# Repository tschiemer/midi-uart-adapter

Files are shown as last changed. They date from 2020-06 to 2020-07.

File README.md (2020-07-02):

# midi-uart-adapter

PCB layout for a simple MIDI (In-Through-Out) / UART - Adapter according to MIDI 1.0 Specification

Does not directly include footprints for MIDI or TRS plugs but rather provides headers such as to more easily allow customization.

Also allows to use different voltage levels for RX, TX respectively (please use different resistors according to recommendations).

https://github.com/tschiemer/midi-uart-adapter

According to simple table-top tests using a Behringer BCF2000 all three connections (in, through, out) work as expected.

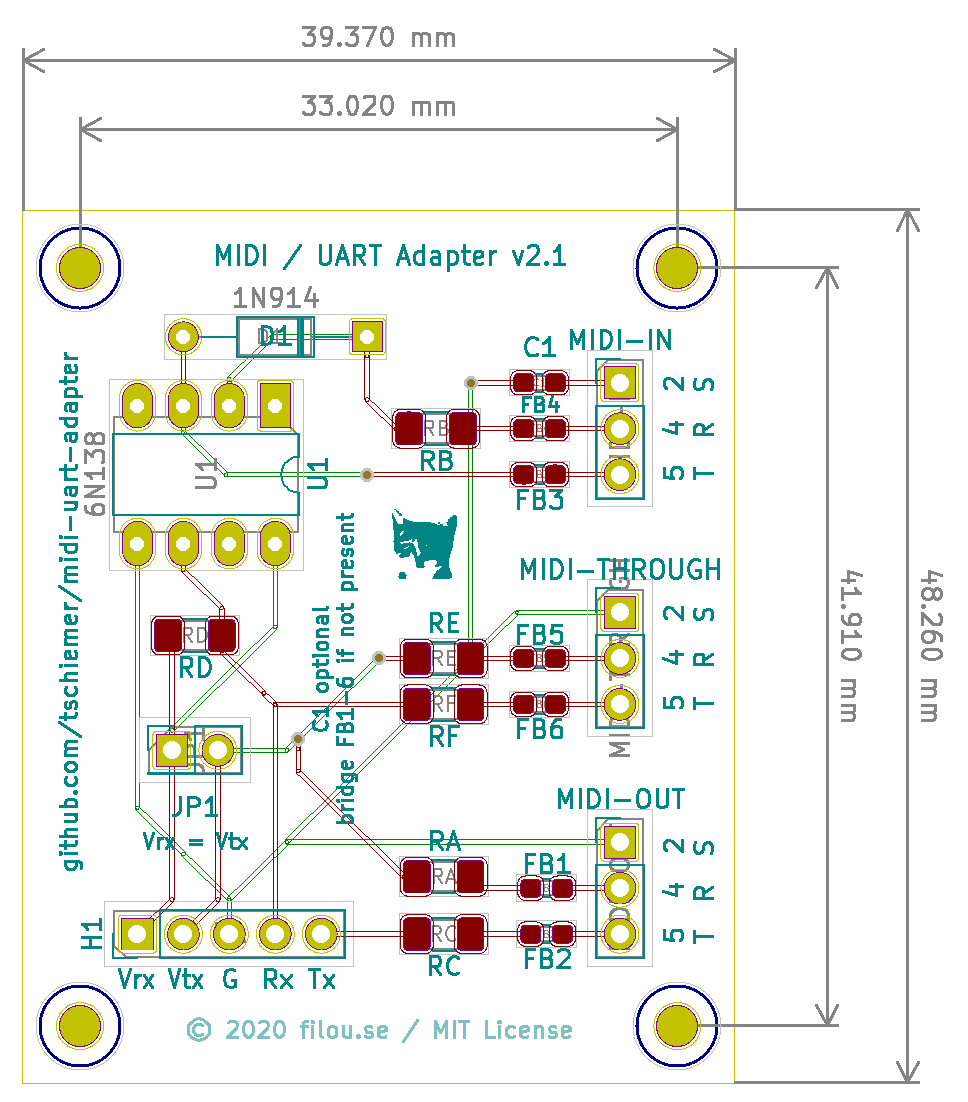
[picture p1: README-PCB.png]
PCB


## Parts

- [LITEON 6N138](https://datasheet.octopart.com/6N139-Lite-On-datasheet-8327661.pdf) or [ONSEMI 6N138](https://www.onsemi.com/pub/Collateral/HCPL2731-D.PDF) Octocoupler
- [ONSEMI 1N914](https://www.onsemi.com/pub/Collateral/1N914-D.PDF) Laser Diode
- Resistors (RA, RB, RC, RD, RE, RF) when Vrx = Vtx = 5V: 220 Ohm 5% 0.25W, Package 1206 (3216 Metric) (ex. [ Bourns Inc. CR1206-FX-2200ELF](https://www.bourns.com/docs/product-datasheets/CRxxxxx.pdf) )
- *Optional* Ferrite Beads (FB1-6), 1kOhm @ 1MHz, Package 0603 (1608 Metric) (ex. [TDK Corporation MMZ1608Y102BTA00](https://product.tdk.com/en/search/emc/emc/beads/info/print_pdf)), bridge if not used
- *Optional* ~~Capacitor (C1), 0.1UF, Package 0201 (0603 Metric) (ex. [Murata Electronics GRM033C80J104KE15D](https://search.murata.co.jp/Ceramy/image/img/A01X/G101/ENG/GRM033C80J104KE15-01A.pdf)), leave unconnected if not used (works, but too *tiny* package size to solder by hand; well, it's possible ;) )~~
- *Optional* Capacitor (C1), 0.1UF, Package 0603 (1608 Metric) (ex. [KEMET C0603C104K4RACTU](https://www.digikey.com/product-detail/en/kemet/C0603C104K4RACTU/399-1096-1-ND/411371)), leave unconnected if not used

The optional parts (ferrite beads and capacitor) are intended to surpress EMI etc.

## Connections

### H1 (Header 1)

| Pin | Description |
|---|---|
| Vrx | Receiver voltage (standard: +5V) |
| Vtx | Transmitter voltage (standard: +5V) |
| G | Ground |
| Rx | UART RX* |
| Tx | UART TX* |

*According to standard: 31.25 (+/- 1%) Kbaud, asynchronous, with a start bit, 8 data bits (D0 to D7), and a stop bit

*Note* if you are using different voltages than 5V (ie 3.3V) you need other resistor values. Also see electrical specs for suggestion.

### Midi-In/-Through/-Out

| DIN-5pole 180deg Pin* | TRS Connector |
|---|---|
| 2 | T |
| 4 | R |
| 5 | S |

*Pins 1 and 3 are not connected.

## Changelog

v2.1
- Reduced size to fit into 4x5cm
- Added license on silkscreen

v2.0
- Removed unnecessary header pins
- More compact / smaller board size

## References

- [MIDI Electrical Specification Update [2014]](https://www.midi.org/downloads?item_id=100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)
- [Specification for Use of "TRS" Connectors with MIDI Devices](https://www.midi.org/downloads?item_id=171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)

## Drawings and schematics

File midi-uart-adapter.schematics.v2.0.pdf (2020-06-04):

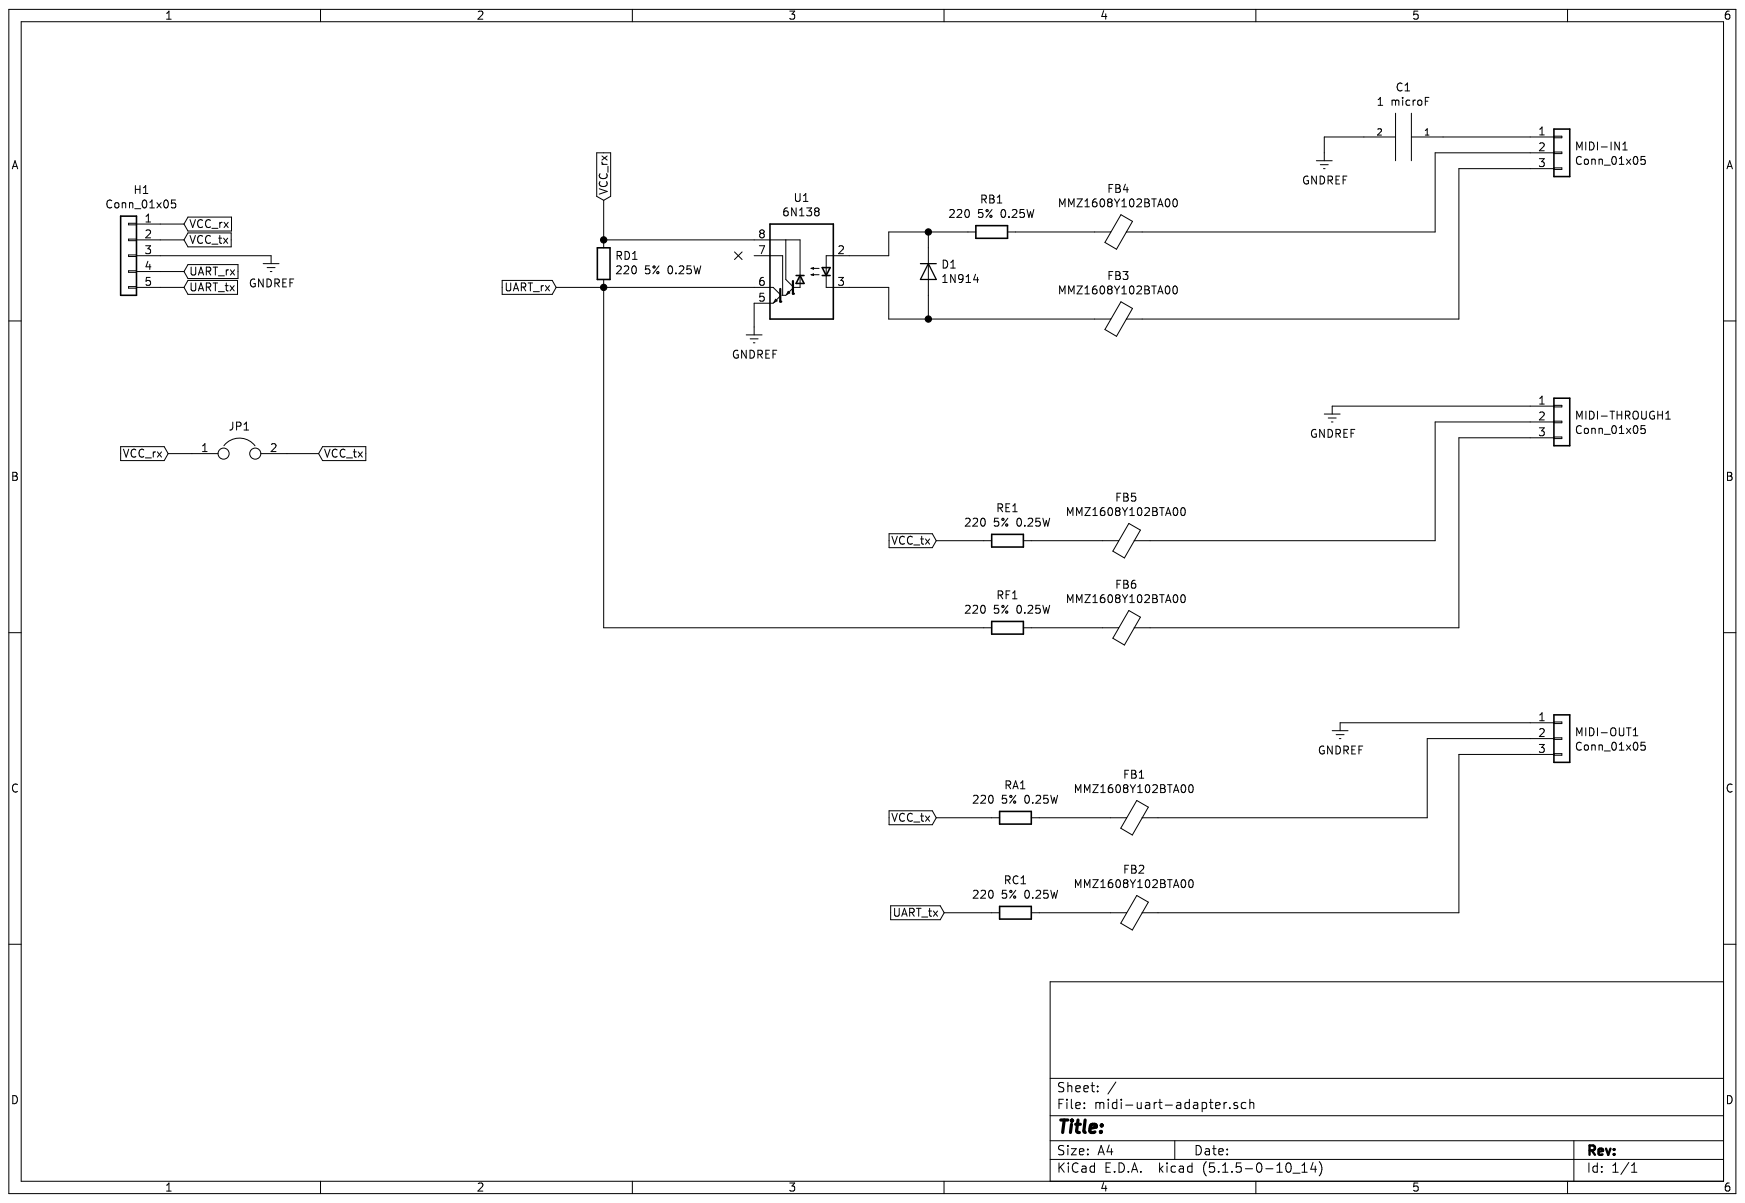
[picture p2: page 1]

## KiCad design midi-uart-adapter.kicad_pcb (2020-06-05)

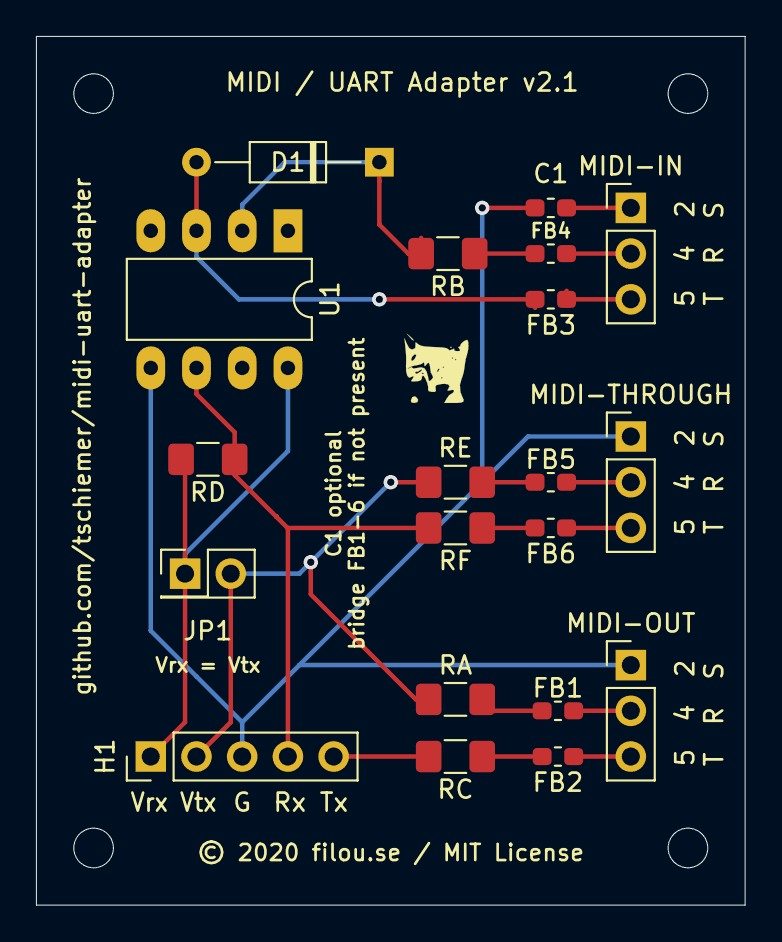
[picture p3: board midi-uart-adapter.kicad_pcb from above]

Board: 2 copper layers, 39.4 x 48.3 mm, 20 parts (0 on the bottom side), 19 nets.

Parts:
C1: 1 microF; C_0603_1608Metric_Pad1.05x0.95mm_HandSolder
D1: 1N914; D_DO-35_SOD27_P10.16mm_Horizontal
FB1, FB2, FB3, FB4, FB5, FB6: MMZ1608Y102BTA00; R_0603_1608Metric_Pad1.05x0.95mm_HandSolder
H1: Conn_01x05; PinHeader_1x05_P2.54mm_Vertical
JP1: VCC_rx - VCC_tx; PinHeader_2x01_P2.54mm_Vertical
MIDI-IN: Conn_01x05; PinHeader_1x03_P2.54mm_Vertical
MIDI-OUT: Conn_01x05; PinHeader_1x03_P2.54mm_Vertical
MIDI-THROUGH: Conn_01x05; PinHeader_1x03_P2.54mm_Vertical
RA: 220 5% 0.25W; R_1206_3216Metric_Pad1.42x1.75mm_HandSolder
RB: 220 5% 0.25W; R_1206_3216Metric_Pad1.42x1.75mm_HandSolder
RC: 220 5% 0.25W; R_1206_3216Metric_Pad1.42x1.75mm_HandSolder
RD: 220 5% 0.25W; R_1206_3216Metric_Pad1.42x1.75mm_HandSolder
RE: 220 5% 0.25W; R_1206_3216Metric_Pad1.42x1.75mm_HandSolder
RF: 220 5% 0.25W; R_1206_3216Metric_Pad1.42x1.75mm_HandSolder
U1: 6N138; DIP-8_W7.62mm_LongPads

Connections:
GNDREF: C1.2, H1.3, MIDI-OUT.1, MIDI-THROUGH.1, U1.5
unnamed: C1.1, MIDI-IN.1
unnamed: D1.1, RB.2, U1.2
unnamed: D1.2, FB3.2, U1.3
unnamed: FB1.1, MIDI-OUT.2
unnamed: FB1.2, RA.1
unnamed: FB2.1, MIDI-OUT.3
unnamed: FB2.2, RC.1
unnamed: FB3.1, MIDI-IN.3
unnamed: FB4.1, MIDI-IN.2
unnamed: FB4.2, RB.1
unnamed: FB5.1, MIDI-THROUGH.2
unnamed: FB5.2, RE.1
unnamed: FB6.1, MIDI-THROUGH.3
unnamed: FB6.2, RF.1
UART_rx: H1.4, RD.1, RF.2, U1.6
UART_tx: H1.5, RC.2
VCC_rx: H1.1, JP1.1, RD.2, U1.8
VCC_tx: H1.2, JP1.2, RA.2, RE.2

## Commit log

2020-05-31 first hw commit
    [midi-uart-adapter.kicad_pcb, midi-uart-adapter.sch]
2020-05-31 C2 -> C1 fix, dimensions
    [midi-uart-adapter.kicad_pcb]
2020-05-31 C2 -> C1
    [midi-uart-adapter.sch]
2020-05-31 added pdf schematics file
2020-06-05 UART settings

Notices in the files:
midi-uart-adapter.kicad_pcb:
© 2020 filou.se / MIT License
